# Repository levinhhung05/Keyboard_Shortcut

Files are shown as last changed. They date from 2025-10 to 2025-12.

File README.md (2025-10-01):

# Keyboard_Shortcut
Mục đích: Phát triển một bàn phím thông minh để thực thi các tác vụ và phím tắt một cách nhanh chóng, giúp tối ưu hóa trải nghiệm và nâng cao năng suất làm việc.

Thành phần chính:
- Vi điều khiển trung tâm: ATMEGA 328P.
- Thiết bị nhập liệu: Bàn phím ma trận 4x4 và 2 bộ encoder.
- Nguyên lý hoạt động:
  + Vi điều khiển (MCU) đọc dữ liệu đầu vào từ bàn phím và encoder.
  + Dữ liệu được truyền đến PC/Laptop thông qua giao tiếp UART.
  + Chương trình Python trên máy tính sẽ nhận dữ liệu này và thực hiện các hành động tương ứng như nhấn tổ hợp phím, điều khiển âm lượng, hoặc mở ứng dụng.

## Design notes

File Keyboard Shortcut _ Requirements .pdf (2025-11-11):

KEYBOARD SHORTCUT

1.Introduction ( Giới thiệu)
Là một thiết bị nhập liệu rút gọn phục vụ cho việc thực hiện các phím tắt và thao tác nhanh trên máy tính, thông qua bàn phím ma trận 4x4 kết hợp với hai bộ mã hóa quay (Rotary Encoder). Thiết bị cho phép người dùng kích hoạt các lệnh như sao chép, dán, mở phần mềm, điều chỉnh âm lượng hoặc phóng to-thu nhỏ chỉ với một thao tác bấm phím hoặc xoay núm.

2.Functional Requirements

Number | Description | Note
FR1 | Hệ thống phải cho phép thực hiện thao tác phím tắt nhanh trên máy tính thông qua bàn phím ma trận 4x4
FR1.1 | Mỗi phím trên bàn phím ma trận 4x4 có thể được ánh xạ (mapping) thành tổ hợp phím tùy chỉnh
FR1.2 | MCU phải thực hiện thuật toán quét bàn phím để phát hiện phím nhấn chính xác theo thời gian thực
FR1.3 | Khi người dùng nhấn phím, dữ liệu phải được gửi đến PC qua UART ngay lập tức.
FR1.4 | Python phải nhận và thực thi đúng hành động được cấu hình tương ứng với mã phím.

FR2 | Hệ thống hỗ trợ điều khiển bằng Rotary Encoder.
FR2.1 | Encoder phải nhận biết chính xác hướng xoay (clockwise/counter–clockwise
FR2.2 | Khi xoay encoder, hệ thống phải gửi mã điều khiển tương ứng lên PC (ví dụ tăng/giảm volume, zoom in/out).
FR2.3 | Nút nhấn trên encoder phải hoạt động như phím chức năng riêng (ví dụ reset zoom hoặc mute)
FR3 | Hệ thống phải truyền dữ liệu giữa MCU và PC qua UART
FR3.1 | Tốc độ truyền dữ liệu UART phải được thiết lập ở mức 9600 baud.
FR3.2 | Dữ liệu truyền phải ở dạng mã ký tự hoặc chuỗi đơn giản để Python dễ phân tích.
FR4 | Phần mềm trên PC phải thực hiện các hành động hệ thống tương ứng.
FR4.1 | Cho phép thực hiện tổ hợp phím như: Ctrl + C, Ctrl + V, Ctrl + A, Alt + F4,…
FR4.2 | Cho phép mở ứng dụng hoặc website qua lệnh Python (subprocess hoặc webbrowser)
FR4.3 | Hỗ trợ điều khiển âm lượng hệ thống qua pyautogui (volumeup, volumedown, mute).
FR5 | Hệ thống phải cho phép tùy chỉnh chức năng các phím.
FR5.1 | Người dùng có thể chỉnh sửa trực tiếp mã Python để thay đổi hành động của từng phím
FR5.2 | Hệ thống phải dễ dàng mở rộng để thêm phím hoặc chức năng mới sau này

3.Non – Functional Requirements

Number | Description | Note
N-FR1 | Hệ thống phải có thời gian phản hồi ≤ 500 ms từ lúc người dùng thao tác đến khi lệnh được thực thi trên máy tính.
N-FR2 | Dữ liệu truyền qua UART phải ổn định, không bị nhiễu, không mất gói trong điều kiện hoạt động bình thường
N-FR3 | Chương trình Python trên PC phải hoạt động liên tục ≥ 300 giờ mà không cần khởi động lại
N-FR4 | Hệ thống phải tương thích với Windows hoặc Linux, không yêu cầu cài đặt thêm driver đặc biệt.
N-FR5 | Thiết bị phải tiêu thụ dòng điện ≤ 100 mA ở 5V để đảm bảo an toàn khi cấp nguồn qua cổng USB
N-FR6 | Kích thước mạch phải gọn, có thể đặt trên bàn làm việc mà không chiếm nhiều diện tích
N-FR7 | Các phím trên bàn phím ma trận phải có độ bền tối thiểu 50.000 lần nhấn
N-FR8 | Encoder phải vận hành mượt, không bị nhảy bước hoặc rung nhiễu khi xoay nhanh
N-FR9 | Thiết bị phải hoạt động ổn định trong dải nhiệt độ 0°C – 50°C

### 4. System architecture

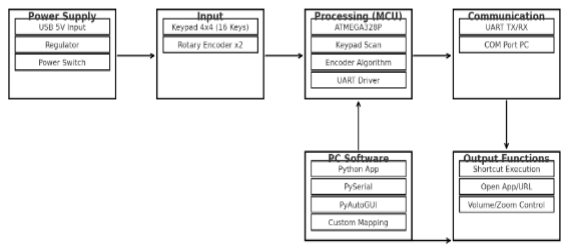
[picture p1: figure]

5.Use case modelling
Use case name | Thực hiên phím tắt bằng Keypad
Use case ID | UC01
Scope | Keyboard Shorcut System
Primary Actor | User
Stakeholder & Interest | User: muốn thao tác nhanh hơn so với dùng bàn phím hoặc chuột. Hệ thống: phải nhận và truyền tín hiệu chính xác, không chậm trễ.
Preconditions | Thiết bị đã được kết nối với máy tính qua UART. Python Script đang chạy
Postconditions | Lệnh phím tắt được thực thi trên máy tính

Main Flow of Events | 1. User nhấn một phím trên keypad. 2. MCU quét phím và mã hóa giá trị phím. 3. MCU gửi mã phím qua UART đến PC. 4. Chương trình Python nhận mã và thực hiện tổ hợp phím tương ứng (VD: Ctrl+C, Alt+F4)
Alternative Flow | User nhấn giữ phím → hệ thống có thể thực thi hành động lặp theo thiết kế (nếu cấu hình)
Exception Flows | Nếu Python không nhận được dữ liệu UART → không có hành động nào xảy ra
Special Requirements | Thời gian phản hồi ≤ 500 ms
Use case name | Điều chỉnh thông số bằng Encoder
Use case ID | UC02
Scope | Keyboard Shorcut System
Primary Actor | User
Stakeholder & Interest | User: muốn chỉnh nhanh các giá trị như âm lượng, zoom, cuộn nội dung

Preconditions | Encoder phải được MCU đọc tín hiệu chính xác (A/B xung)
Postconditions | Thao tác điều chỉnh được thực hiện trên máy tính.
Main Flow of Events | 1. User xoay encoder. 2. MCU đọc hướng xoay và đếm bước xung. 3. MCU gửi ký tự điều khiển tương ứng qua UART (VD: 'X' = Volume Up). 4. Python nhận và thực thi lệnh (volumeup, zoom in/out…)
Alternative Flow | User nhấn nút trên encoder để thực hiện hành động phụ (VD: mute, reset zoom)
Exception Flows | Xung encoder nhiễu → MCU sử dụng debounce logic để lọc.
Special Requirements | Tốc độ xử lý xoay nhanh không được bỏ xung.
Use case name | Tùy chỉnh chức năng phím (Custom Mapping)
Use case ID | UC03
Scope | Keyboard Shorcut System

Primary Actor | User
Stakeholder & Interest | User: muốn cá nhân hóa phím theo thói quen sử dụng.
Preconditions | User truy cập file Python để chỉnh sửa mapping.
Postconditions | Cấu hình mới được lưu và có hiệu lực ngay khi chạy lại script.
Main Flow of Events | 1. User mở file Python mapping. 2. User sửa mã phím → lệnh tương ứng mới. 3. Lưu file và khởi chạy lại chương trình Python. 4. Keypad hoạt động theo cấu hình mới.
Alternative Flow | Có thể lưu nhiều profile mapping để chuyển đổi.
Exception Flows | Nếu user nhập sai mã lệnh, Python có thể báo lỗi và không thực thi.
Special Requirements | File cấu hình phải đơn giản, dễ chỉnh sửa.

6.Hardware Requirements

Vi điều khiển (Atmega328P):

- MCU 8 bit,xung nhịp tối đa 20MHz,bộ nhớ flash 32KB,SRAM 2KB,EEPROM 1KB
- Số chân I/O là 23 chân,đáp ứng kết nối keypad và encoder
- Tích hợp UART để truyền dữ liệu sang PC

Keypad ma trận 4x4(16 phím)
- Sử dụng 8 chân GPIO để quét ma trận
- Điện áp tương thích MCU 3-5V
- Cấu trúc 4 hàng x 4 cột,tổng 16 phím

Rotary Encoder ( 2 bộ)

- Độ phân giải :khoảng 20pulses/rev
- Mỗi encoder gồm kênh A-B và nút nhấn
- Đảm bảo kết nối Encoder 1 -> PD0,PD2,PD4;Encoder 2->PD1,PD3,PD5
- Điều chỉnh nhanh các chức năng như:tăng/giảm volume;zoom in/zoom out

Button(tích hợp trong Encoder)
- Sử dụng cơ chế debounce để giảm nhiễu

7.Software Requiments

Firmware trên Atmega328P

- Khởi tạo cổng I/O,cấu hình các chân keypad và encoder
- Truyền dữ liệu qua UART đến PC với tốc độ 9600bps
- Thực hiện thuật toán quét bàn phím ma trận 4x4 để phát hiện phím nhấn theo thời gian thực

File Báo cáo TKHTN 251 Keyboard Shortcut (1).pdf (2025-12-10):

### ĐẠI HỌC QUỐC GIA TP. HỒ CHÍ MINH

### TRƯỜNG ĐẠI HỌC BÁCH KHOA

### KHOA ĐIỆN – ĐIỆN TỬ

### BỘ MÔN ĐIỆN TỬ

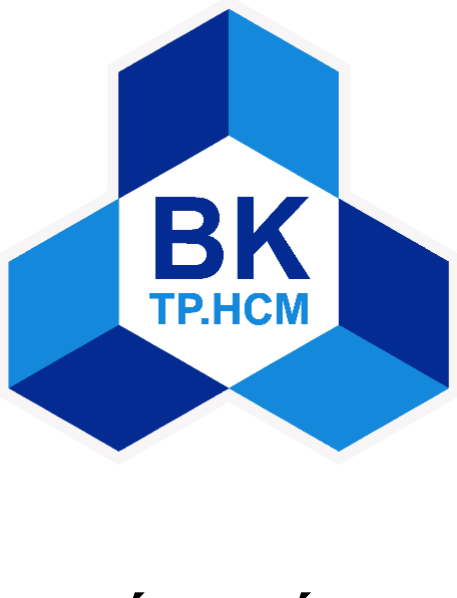
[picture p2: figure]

### BÁO CÁO

### THIẾT KẾ HỆ THỐNG NHÚNG

### KEYBOARD SHORTCUT

### Nhóm 7 GVHD: Ths Bùi Quốc Bảo

TP. Hồ Chí Minh, Tháng 12 Năm 2025

Thiết kế hệ thống nhúng | GVHD :Ths Bùi Quốc Bảo

MỤC LỤC

CHƯƠNG 1 : TỔNG QUAN
LỜI NÓI ĐẦU

Trong thời đại ngày nay, giữa sự phát triển nhanh chóng của các thiết bị điện tử, trải nghiệm người dùng cũng đang được cải thiện tương ứng. Một trong những trải nghiệm người dùng được nhấn mạnh là tốc độ vận hành, đặc biệt là trong các lĩnh vực chuyên môn như thiết kế kỹ thuật số, đòi hỏi phải thực hiện nhanh chóng các hành động cụ thể. Vì lý do này, nhóm chúng tôi giới thiệu một giải pháp: bàn phím tắt, được thiết kế để giúp người dùng thực hiện nhanh chóng một loạt hành động thông qua một bộ phím tắt được thiết lập sẵn. Hơn nữa, sản phẩm cho phép người dùng tùy chỉnh và cấu hình các phím tắt để phù hợp với sở thích cá nhân linh hoạt.

### 1.1 Giới thiệu về dự án

Trong quá trình học tập và làm việc, hoạt động của sinh viên luôn gắn liền với máy tính và việc sử dụng các chức năng có sẵn thông qua các phím tắt. Xuất phát từ nhu cầu cá nhân này và đồng thời với việc học tập môn Thiết kế Hệ thống Nhúng trong học kỳ hiện tại, nhóm 7 đã quyết định chọn đề tài “ Keyboard Shortcut ”.

### 1.2 Mục đích của dự án

Mục tiêu chính của dự án này là phát triển một bàn phím thông minh, kết hợp tính linh hoạt của bàn phím ma trận 4x4 với khả năng điều khiển đa chức năng của hai bộ mã hóa quay. Điều này sẽ cung cấp một công cụ nhập liệu hiệu quả, tối ưu hóa trải nghiệm của người dùng và nâng cao năng suất làm việc hàng ngày.

### 1.3 Lý do chọn dự án

Nhóm 7 chúng em chọn chủ đề này dựa trên kinh nghiệm cá nhân và nhu cầu thường xuyên sử dụng các chức năng khác nhau có sẵn trên máy tính. Là sinh viên kỹ thuật, các thành viên nhóm thường xuyên tiếp xúc với các công nghệ mới, đòi hỏi khả năng sáng tạo để hợp lý hóa quy trình làm việc. Việc tích hợp bàn phím ma trận và bộ mã hóa quay trong bàn phím tắt không chỉ tối ưu hóa thao tác nhập liệu mà còn mở ra nhiều khả năng đa chức năng. Điều này rất quan trọng trong phạm vi của môn học "Thiết kế Hệ thống Nhúng", nơi nhóm có thể áp dụng dự án vào các dự án cá nhân hoặc thậm chí là công việc nghiên cứu và phát triển. Các khóa học cơ bản về điện tử, vi xử lý và thiết kế kỹ thuật số đã cung cấp cho nhóm một nền tảng lý thuyết vững chắc và các kỹ thuật thiết kế cho hệ thống nhúng. Dự án này đóng vai trò là cầu nối giữa kiến thức đã học và ứng dụng thực tế.

### 1.4 Thành viên nhóm – nhiệm vụ - đánh giá % thực hiện

Họ và Tên | MSSV | Nhiệm vụ | Đánh giá
Trần Phạm Ngọc Vũ | 2214010 | Lên ý tưởng, soạn nội dung, hardware design | 100%
Lê Vĩnh Hưng | 2010305 | Software design ,lên ý tưởng,test sản phẩm/demo | 100%

CHƯƠNG 2:TỔNG QUAN HỆ THỐNG

### 2.1 Requirements của hệ thống

### 2.1.1 Functional Requirements

Number | Description
FR1 | Hệ thống phải cho phép thực hiện thao tác phím tắt nhanh trên máy tính thông qua bàn phím ma trận 4x4
FR1.1 | Mỗi phím trên bàn phím ma trận 4x4 có thể được ánh xạ (mapping) thành tổ hợp phím tùy chỉnh
FR1.2 | MCU phải thực hiện thuật toán quét bàn phím để phát hiện phím nhấn chính xác theo thời gian thực
FR1.3 | Khi người dùng nhấn phím, dữ liệu phải được gửi đến PC qua UART ngay lập tức.
FR1.4 | Python phải nhận và thực thi đúng hành động được cấu hình tương ứng với mã phím.
FR2 | Hệ thống hỗ trợ điều khiển bằng Rotary Encoder.
FR2.1 | Encoder phải nhận biết chính xác hướng xoay (clockwise/counter–clockwise
FR2.2 | Khi xoay encoder, hệ thống phải gửi mã điều khiển tương ứng lên PC (ví dụ tăng/giảm volume, zoom in/out).
FR2.3 | Nút nhấn trên encoder phải hoạt động như phím chức năng riêng (ví dụ reset zoom hoặc mute)
FR3 | Hệ thống phải truyền dữ liệu giữa MCU và PC qua UART

FR3.1 | Tốc độ truyền dữ liệu UART phải được thiết lập ở mức 9600 baud.
FR3.2 | Dữ liệu truyền phải ở dạng mã ký tự hoặc chuỗi đơn giản để Python dễ phân tích.
FR4 | Phần mềm trên PC phải thực hiện các hành động hệ thống tương ứng.
FR4.1 | Cho phép thực hiện tổ hợp phím như: Ctrl + C, Ctrl + V, Ctrl + A, Alt + F4,…
FR4.2 | Cho phép mở ứng dụng hoặc website qua lệnh Python (subprocess hoặc webbrowser)
FR4.3 | Hỗ trợ điều khiển âm lượng hệ thống qua pyautogui (volumeup, volumedown, mute).
FR5 | Hệ thống phải cho phép tùy chỉnh chức năng các phím.
FR5.1 | Người dùng có thể chỉnh sửa trực tiếp mã Python để thay đổi hành động của từng phím
FR5.2 | Hệ thống phải dễ dàng mở rộng để thêm phím hoặc chức năng mới sau này

### 2.1.2 Non – Functional Requirements

Number | Description
N-FR1 | Hệ thống phải có thời gian phản hồi ≤ 500 ms từ lúc người dùng thao tác đến khi lệnh được thực thi trên máy tính.

N-FR2 | Dữ liệu truyền qua UART phải ổn định, không bị nhiễu, không mất gói trong điều kiện hoạt động bình thường
N-FR3 | Chương trình Python trên PC phải hoạt động liên tục ≥ 300 giờ mà không cần khởi động lại
N-FR4 | Hệ thống phải tương thích với Windows hoặc Linux, không yêu cầu cài đặt thêm driver đặc biệt.
N-FR5 | Thiết bị phải tiêu thụ dòng điện ≤ 100 mA ở 5V để đảm bảo an toàn khi cấp nguồn qua cổng USB
N-FR6 | Kích thước mạch phải gọn, có thể đặt trên bàn làm việc mà không chiếm nhiều diện tích
N-FR7 | Các phím trên bàn phím ma trận phải có độ bền tối thiểu 50.000 lần nhấn
N-FR8 | Encoder phải vận hành mượt, không bị nhảy bước hoặc rung nhiễu khi xoay nhanh
N-FR9 | Thiết bị phải hoạt động ổn định trong dải nhiệt độ 0°C – 50°C

### 2.2 Block diagram của hệ thống

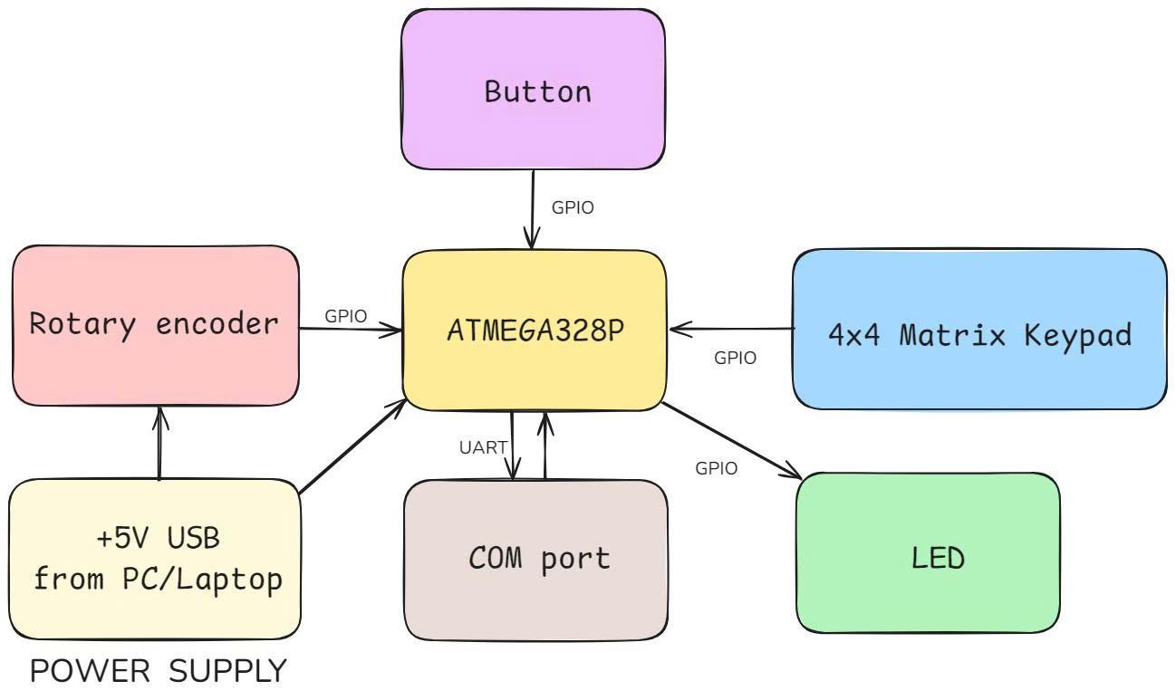
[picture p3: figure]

1. Bàn phím ma trận: Khi người dùng nhấn một phím trên bàn phím ma trận, nó sẽ gửi mã ASCII tương ứng đến MCU.
2. Bộ mã hóa: Khi xoay bộ mã hóa theo chiều kim đồng hồ hoặc ngược chiều kim đồng hồ, nó sẽ gửi dữ liệu kết quả đến MCU.
3. MCU: Sử dụng thư viện bộ mã hóa để xử lý dữ liệu nhận được từ bộ mã hóa và xử lý dữ liệu từ cả bộ mã hóa và MCU, truyền dữ liệu đã xử lý đến PC/Máy tính xách tay thông qua giao tiếp UART.

2.3 . Schematic của hệ thống

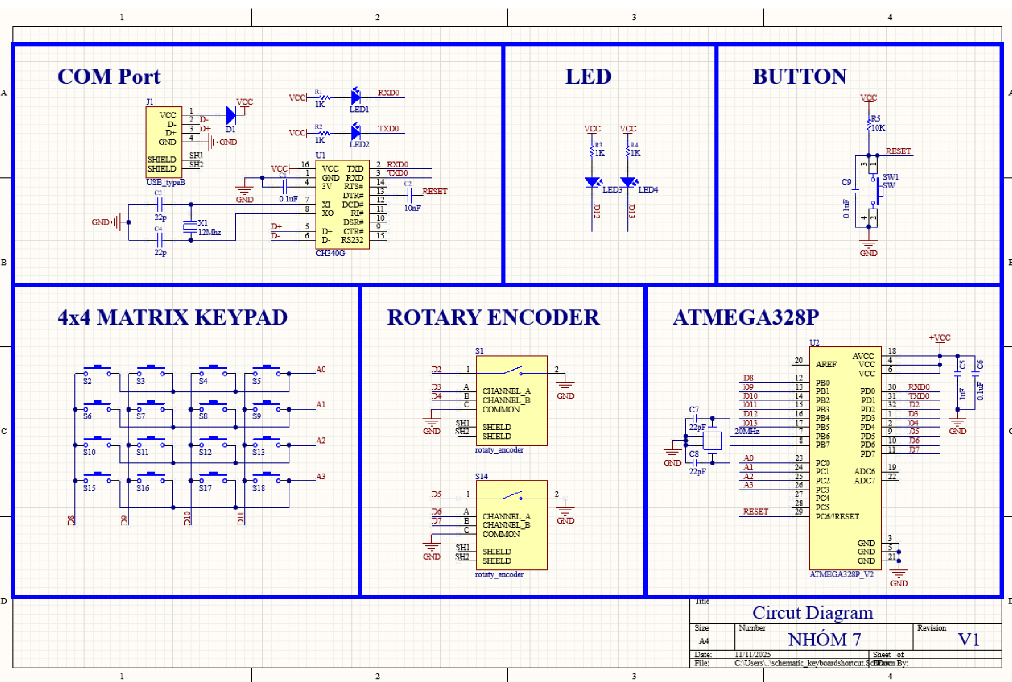
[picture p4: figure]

CHƯƠNG 3 : THIẾT KẾ PHẦN CỨNG

### 3.1 Đặc điểm kỹ thuật của sản phẩm

Function | Thực hiện các tác vụ, phím tắt nhanh chóng
Input | Bàn phím ma trận 4x4
Output | Laptop hoặc PC
User interface | Bàn phím ma trận 4x4
External interface | UART

1. Thuật toán quét bàn phím: Hệ thống phải triển khai thuật toán quét bàn phím để phát hiện chính xác các phím đã nhấn trên ma trận bàn phím 4x4. Thuật toán này chịu trách nhiệm xác định chính xác các phím đã nhấn và thực hiện xử lý thời gian thực.
2. Xử lý thời gian thực: Hệ thống phải hỗ trợ xử lý thời gian thực để đảm bảo phản hồi tức thời với đầu vào của người dùng. Điều này bao gồm giảm thiểu độ trễ trong việc phát hiện các phím đã nhấn và truyền dữ liệu đến PC/Laptop được kết nối.
3. Truyền dữ liệu đến PC/Laptop qua UART: Giao tiếp dữ liệu giữa hệ thống nhúng và PC/Laptop phải được thực hiện qua UART (Bộ thu-phát đồng bộ không đồng bộ toàn cầu). Điều này đảm bảo việc truyền dữ liệu đáng tin cậy và không đồng bộ, tạo điều kiện giao tiếp liền mạch giữa hai thiết bị.
4. Chức năng tùy chỉnh của các phím: Bàn phím tắt phải cung cấp tính linh hoạt trong việc sửa đổi chức năng của từng phím. Tính năng này cho phép người dùng, trong trường hợp này là sinh viên ngành kỹ thuật viễn thông, tùy chỉnh và điều chỉnh bàn phím theo nhu cầu .
5. Thuật toán mã hóa: Hệ thống phải tích hợp một thuật toán mã hóa để xử lý đầu vào từ hai bộ mã hóa quay. Thuật toán phải chuyển đổi chính xác chuyển động quay của các bộ mã hóa thành các hành động có ý nghĩa, nâng cao tương tác của người dùng.

### 3.2 Mô tả phần cứng

Device names | Technical specifications
Giao diện bàn phím số | Temperature Range:0-70 độ C Output :8pins Size :77x 69 mm

ATMEGA 328P | Loại IC :AVR microcontroller Core size : 8 bit Speed: lên đến 20MHz Số chân I/O:23 Program memory size:32KB EEPROM size: 1KB x 8 RAM size :2K x 8 Supply voltage: 1.8V đến 5.5V
Encoder | Supply voltage 3V đến 5V Resolution :20 pulse/rev
1. MCU ATMEGA 328P đọc dữ liệu từ bộ mã hóa và bàn phím ma trận, và gửi dữ liệu đến PC qua UART.
2. 2 Bộ mã hóa điều chỉnh các chức năng điều chỉnh âm lượng, phóng to và thu nhỏ thông qua núm xoay.
3. Bàn phím ma trận 4x4 bao gồm 16 phím, mỗi phím có khả năng điều khiển một thao tác cụ thể hoặc một tổ hợp phím tùy chỉnh.

### 3.3 Các thành phần chi tiết

Bộ mã hóa quay 360 độ

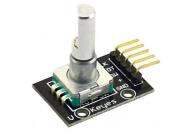
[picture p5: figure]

Mạch âm lượng 360 độ của bộ mã hóa quay là một thành phần quan trọng trong hệ thống điều khiển âm thanh và điện tử, được thiết kế để điều chỉnh âm lượng hoặc các thông số khác một cách linh hoạt và chính xác.

Bàn phím ma trận:

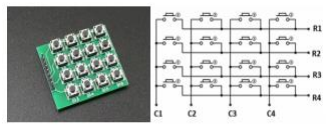
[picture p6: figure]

Khi một phím được nhấn, mạch sẽ tạo một đường dẫn từ hàng tương ứng đến cột. Bộ vi điều khiển hoặc bộ giải mã bàn phím sau đó sẽ đọc các đường dẫn này và xác định phím được nhấn. Mỗi phím có một mã cụ thể được truyền đến hệ thống để xử lý.

### 3.4 Các vấn đề hạn chế

No | Hạn chế
1 | Chi phí thấp, < 1.000.000 VND
2 | Thời gian phản hồi < 600ms
3 | Công suất thấp < 25W

Các vấn đề về chức năng

1. Đảm bảo nhận dạng chính xác và đáng tin cậy các lần nhấn phím để kích hoạt đúng các chức năng đã được ký.

2. Khắc phục các vấn đề liên quan đến việc tùy chỉnh các phím được gán và đảm bảo tích hợp hoàn toàn với phần mềm.

Khi nhấn đồng thời nhiều phím trên cùng một hàng trên bàn phím, bàn phím chỉ ghi nhận phím có giá trị cột thấp nhất

CHƯƠNG 4 : THIẾT KẾ PHẦN MỀM

### 4.1 Mô tả phần mềm

Name | Developer | Application
Proteus | Labcenter Electronics Ltd | Mô phỏng sơ đồ phần cứng với thư viện lớn và đa dạng
Arduino IDE | Arduino community | Đơn giản hóa việc viết mã, tải lên và gỡ lỗi
Visual studio code | Microsoft | Sử dụng Python để nhận tín hiệu từ cổng IO để xử lý mong muốn của người dùng

### 4.2 Flow chart

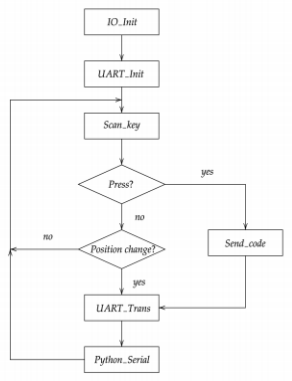
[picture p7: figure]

Giải thích sơ đồ khối:

1. IO init cung cấp thư viện Encoder để nhận biết Bộ mã hóa đang quay hay không và hướng quay của Bộ mã hóa.
2. UART Init khai báo Baudrate cho cổng UART.

3. Phím quét cho phép phát hiện người dùng đã nhấn bàn phím hay chưa. Nếu một phím được nhấn, hãy gửi mã ASCII tương ứng đến MCU.
4. Kiểm tra xem Bộ mã hóa có đang quay hay không và hướng quay của nó, sau đó gửi dữ liệu đến MCU.
5. MCU truyền dữ liệu nhận được đến PC/Laptop qua UART.
6. Kết quả nhận được trên PC/Laptop được xử lý bằng Python sử dụng Python Serial để thực hiện các chức năng tương ứng

### 4.3 Công cụ phần mềm để lập trình và mô phỏng

1. Ngôn ngữ lập trình: C, Python
2. Môi trường phát triển: AVR Studio / Arduino IDE
3. Phần mềm mô phỏng: Proteus hoặc phần mềm mô phỏng tương tự.
4. Phương tiện truyền dữ liệu: Sử dụng mô phỏng cổng COM / giao thức UART trong phần mềm mô phỏng.

CHƯƠNG 5 : KẾT QUẢ THỰC HIỆN

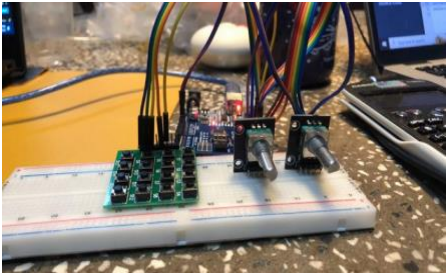
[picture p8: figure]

Video demo của sản phẩm :

…
Ưu điểm
1. Tiết kiệm chi phí sử dụng I/O: Bàn phím ma trận 4x4 cho phép người dùng nhấn đồng thời nhiều phím mà không cần nhiều chân vào/ra. (Một mô-đun 4x4 cần 8 chân so với 16 chân để kết nối từng phím thông thường)
2. Độ tin cậy cao: Với cấu trúc đơn giản và không có bộ phận chuyển động cơ học, bàn phím ma trận thường đảm bảo độ tin cậy cao và tuổi thọ cao.

3. Thân thiện với người dùng: Bàn phím ma trận dễ sử dụng và cài đặt, dễ dàng tích hợp vào nhiều môi trường hệ thống khác nhau với các loại bộ xử lý và bộ điều khiển khác nhau.
4. Tiết kiệm chi phí: Bàn phím ma trận thường có chi phí thấp, khiến chúng trở thành lựa chọn phổ biến trong các ứng dụng có ngân sách hạn chế.

Nhược điểm
1. Số lượng phím hạn chế: Với số lượng phím hạn chế, bàn phím ma trận có thể không phù hợp với các ứng dụng yêu cầu nhiều chức năng hoặc lựa chọn phức tạp.
2. Khả năng nhận dạng phím hạn chế: Trong một số trường hợp, khả năng nhận dạng phím có thể bị hạn chế, đặc biệt là khi nhấn đồng thời nhiều phím trên cùng một hàng.
3. Khả năng chống nước và bụi hạn chế: Một số loại bàn phím ma trận thường không có khả năng chống nước và bụi, điều này có thể gây hạn chế trong môi trường làm việc khắc nghiệt.

CHƯƠNG 6 : KẾT LUẬN
Tóm lại, dự án keyboard shortcut do nhóm 7 chúng em thiết kế đã đạt được mục tiêu chính là thực hiện nhanh chóng các tác vụ và phím tắt thông qua giao diện có thể tùy chỉnh. Nhóm đã triển khai các giải pháp mạnh mẽ để giải quyết nhiều thách thức thiết kế phát sinh trong quá trình phát triển.

Nhìn chung, bàn phím tắt mang lại trải nghiệm người dùng được nâng cao bằng cách cải thiện đáng kể tốc độ hoạt động cho các ứng dụng chuyên biệt. Tính năng tùy chỉnh cũng cho phép linh hoạt đáp ứng các sở thích cá nhân đa dạng.
Trong tương lai, nhóm đặt mục tiêu cải thiện sản phẩm này hơn nữa bằng cách bổ sung kết nối không dây để sử dụng không cần dây. Việc tích hợp các mô-đun Bluetooth sẽ loại bỏ tình trạng dây cáp lộn xộn và mở rộng khả năng tương thích với các thiết bị di động. Với phạm vi đổi mới ngày càng mở rộng, tầm nhìn của nhóm là kết hợp xác thực sinh trắc học như quét vân tay để cho phép nhiều cấu hình tùy chỉnh trên một thiết bị bàn phím. Dự án đầy thách thức này đã mang lại những bài học thực hành vô giá và củng cố năng lực thiết kế hệ thống nhúng của nhóm. Nhóm tự hào đã đạt được các mục tiêu này nhờ nỗ lực không ngừng và tinh thần làm việc nhóm phối hợp.

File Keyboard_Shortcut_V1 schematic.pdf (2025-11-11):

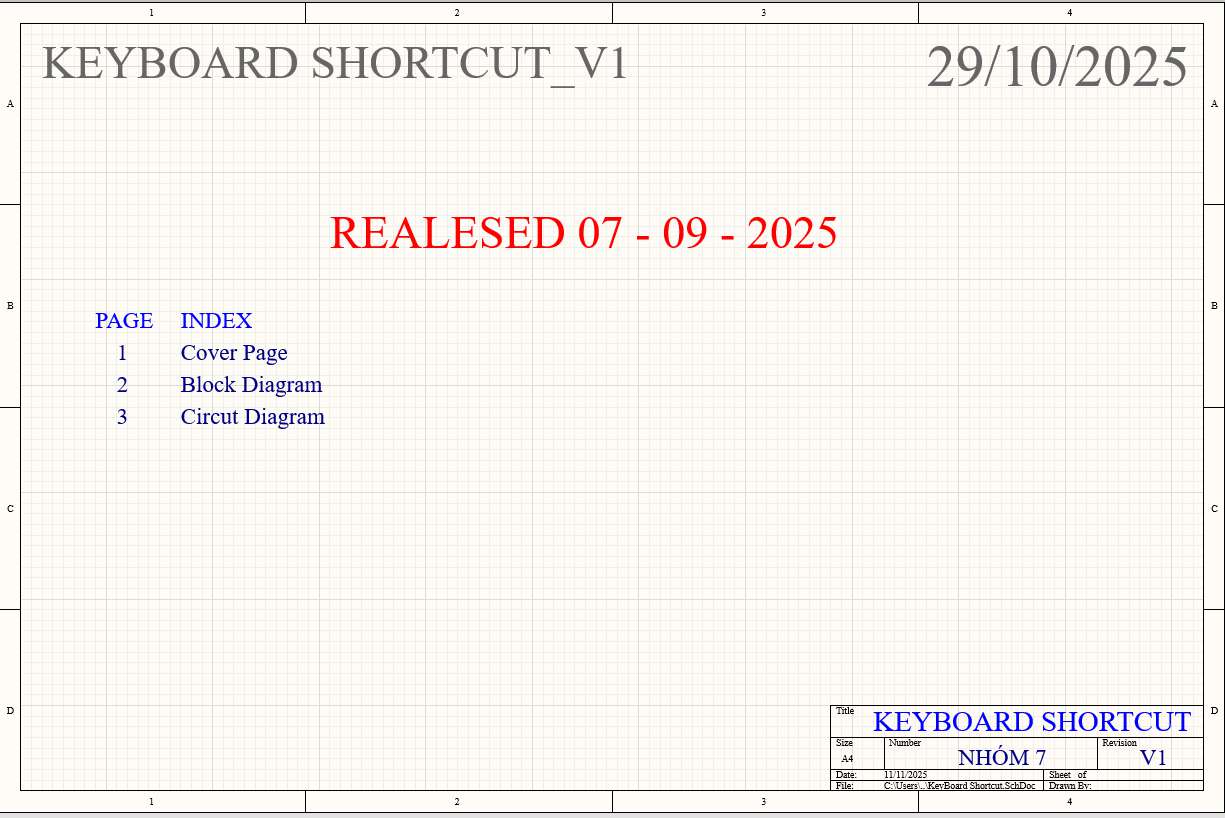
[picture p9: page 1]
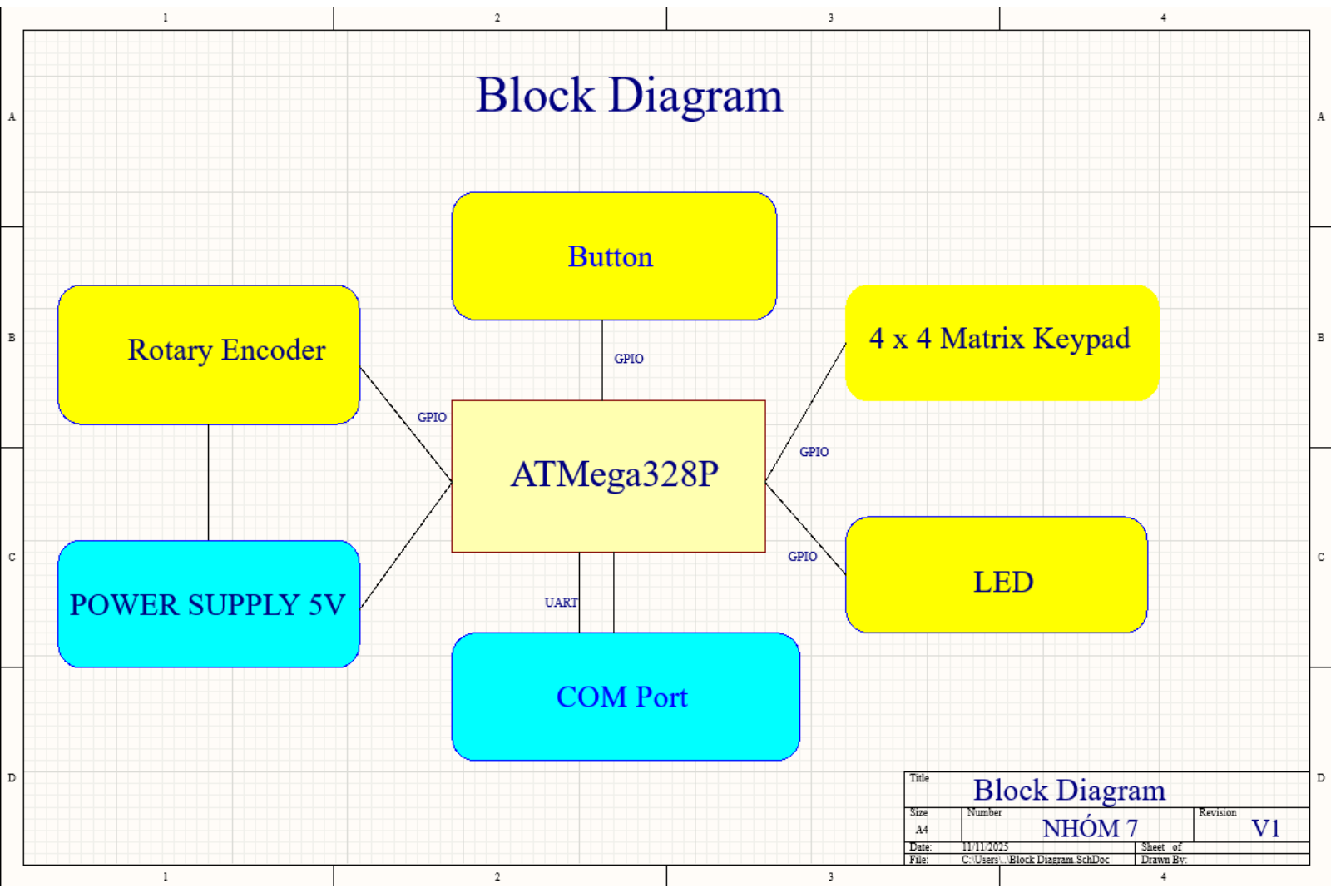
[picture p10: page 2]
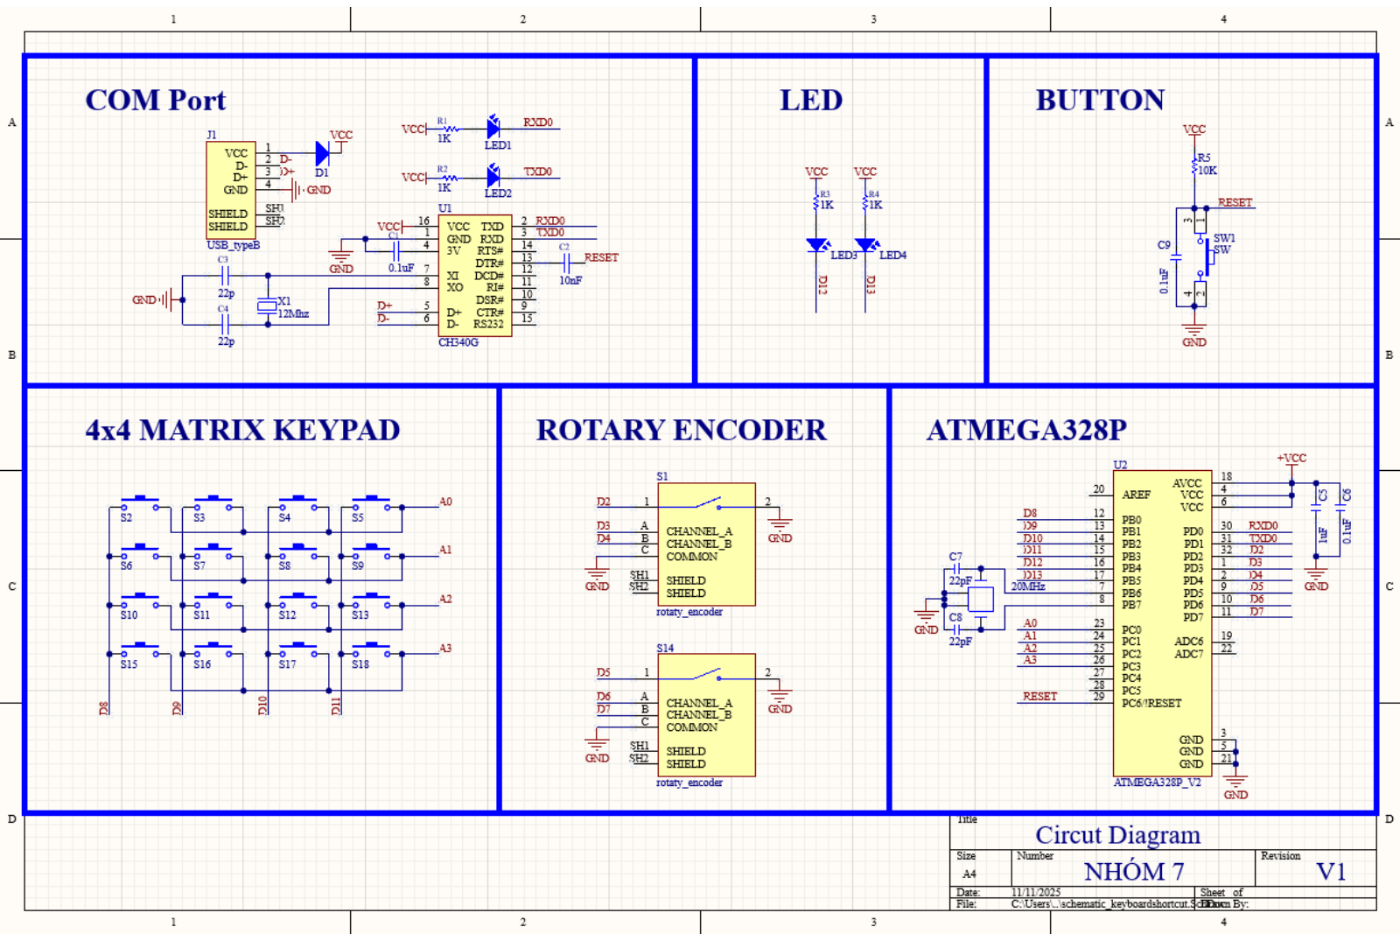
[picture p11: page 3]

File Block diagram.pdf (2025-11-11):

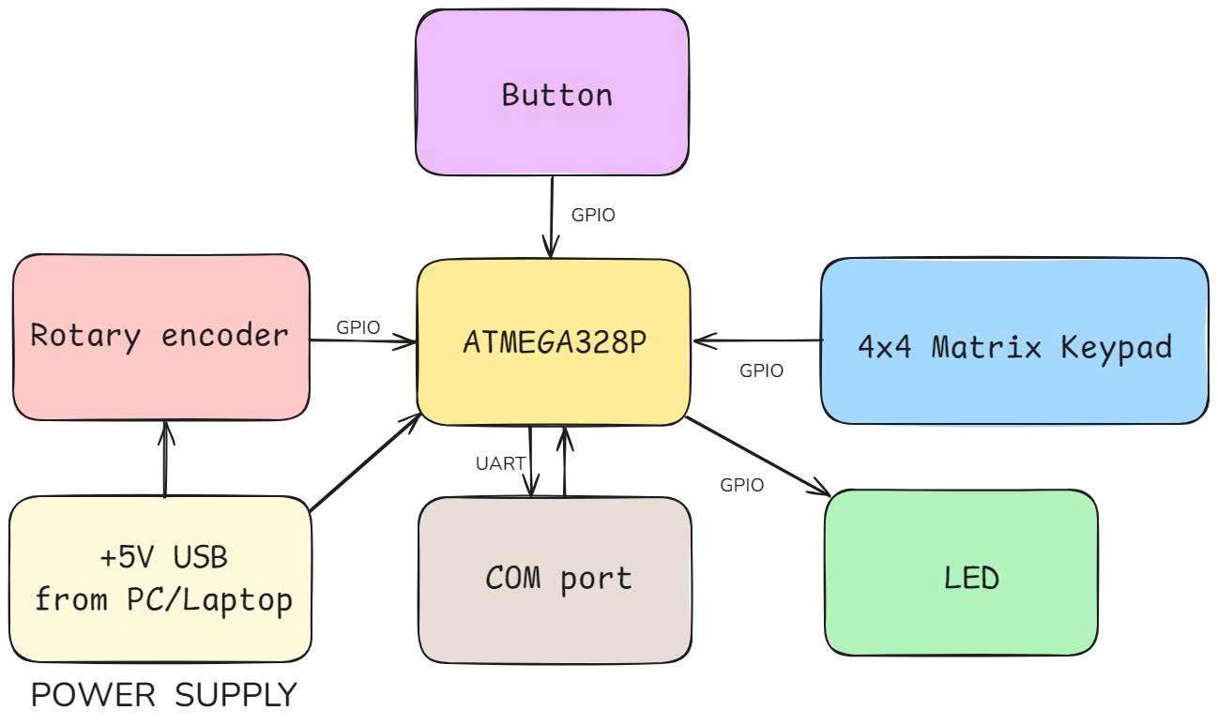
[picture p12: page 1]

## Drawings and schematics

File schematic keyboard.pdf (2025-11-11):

# BUTTON

# VCCD13

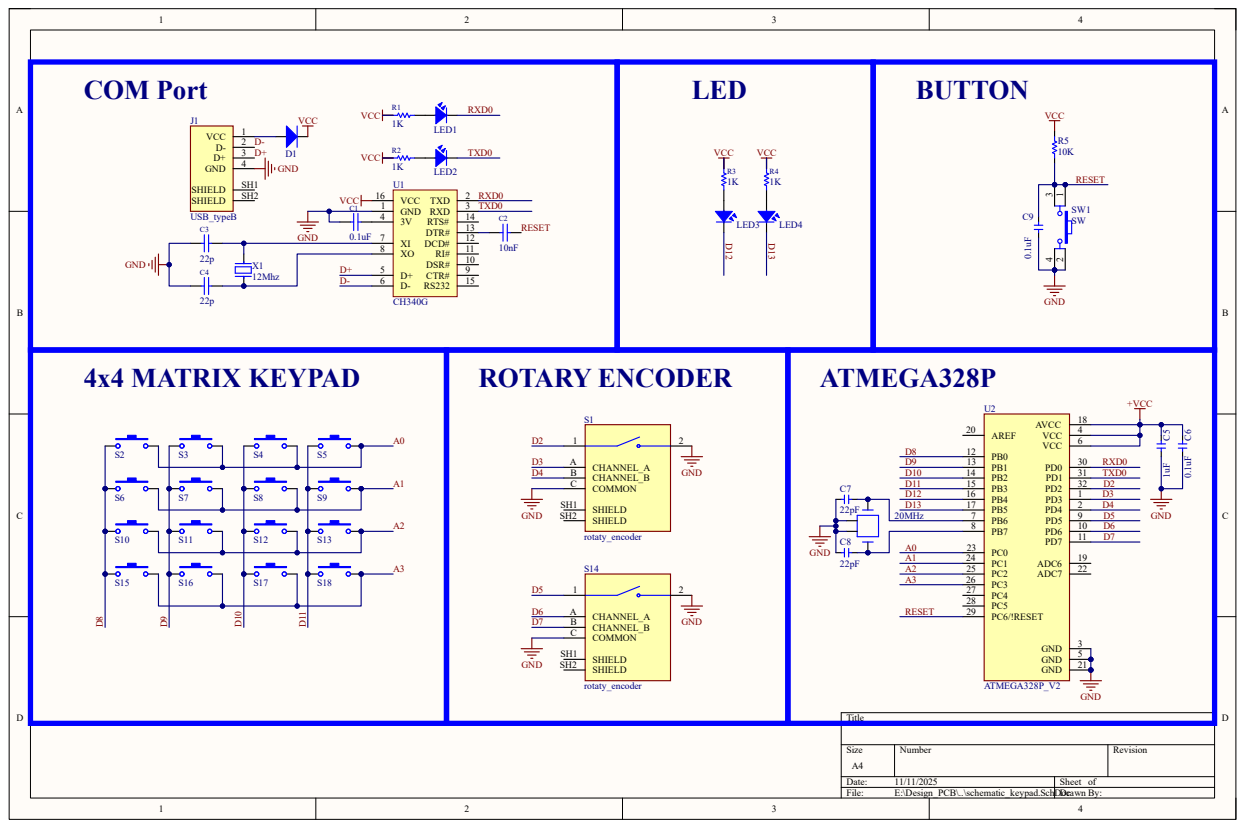
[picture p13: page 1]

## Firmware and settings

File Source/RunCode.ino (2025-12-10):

#define ENCODER_DO_NOT_USE_INTERRUPTS
#include <avr/io.h>
#include <avr/interrupt.h>
#include "lib/Encoder/Encoder.h"
//-----------------------------------------------------------------------------------------------

void IO_Init(){
  //SET PORTB AS INPUT  FOR KEYPAD  3*2
  DDRB  |= (1<<PB0) | (1<<PB1) | (1<<PB2) | (1<<PB3);         //PB0:3 = OUTPUT
  DDRC  &=  ~((1<<PC0) | (1<<PC1) | (1<<PC2) | (1<<PC3));     //PC0:3 = INPUT
  PORTC |= (1<<PC0) | (1<<PC1) | (1<<PC2) | (1<<PC3);
  //SET PORTD AS INPUT FOR ROTATE ENCODER 
  //PD2: INT0 FOR CLK ENCODER 1
  //PD3: INT1 FOR CLK ENCODER 2
  //PD4:PD5 FOR DW ENCODER 1:2
  //PD6:PD7 FOR BUTTON ENCODER  1:2
  DDRD &= ~( (1<<PD2)|(1<<PD3)|(1<<PD4)|(1<<PD5)|(1<<PD6)|(1<<PD7) );
  PORTD = 0XFF;
}
//-------------------------------------------------------------
uint8_t last_key_state = 0; 
uint8_t key_state = 0; 

int8_t Keypad_Scan() {
    // COL = PB0..PB3 (output)
    // ROW = PC0..PC3 (input + pullup)

    // Set all COL pins HIGH
    PORTB |= 0x0F;  // PB0..PB3 = 1

    for (uint8_t col = 0; col < 4; col++) {

        // Pull COL down LOW
        PORTB &= ~(1 << col);
        _delay_us(5);

        uint8_t rowPins = PINC & 0x0F; // đọc PC0..PC3

        if (!(rowPins & (1 << PC0))) return col +  0;  // row 0
        if (!(rowPins & (1 << PC1))) return col +  4;  // row 1
        if (!(rowPins & (1 << PC2))) return col +  8;  // row 2
        if (!(rowPins & (1 << PC3))) return col + 12;  // row 3

        // Pull up
        PORTB |= (1 << col);
    }

    return -1;
}
//-------------------------------------------------------------
void UART_Init() {
    // Baudrate = 9600
    UBRR0H = 0;
    UBRR0L = 103;

    // Active receive and transmit
    UCSR0B = (1 << TXEN0);

    // 8 bit data, 1 bit stop
    UCSR0C = (1 << UCSZ01) | (1 << UCSZ00);
}

void UART_Trans(uint8_t data) {
    while (!(UCSR0A & (1 << UDRE0)));
    // Transmit the character over UART
    UDR0 = data;
}

//-------------------------------------------------------------
Encoder upDown(2,4);
Encoder leftRight(3,5);
long posUpDown = 0; //Position counter for up/down encoder
long posLeftRight = 0; //Position counter for left/right encoder
long posUpDownPrev = 0; //Previous position of up/down encoder
long posLeftRightPrev = 0; //Previous position of left/right encoder

int counterUpDown = 0;
int counterLeftRight = 0;

//-------------------------------------------------------------
int main() {
    int8_t key;
    int8_t last_key = -1;
    uint32_t key_press_time = 0;

    IO_Init();
    UART_Init();
    sei();

    while (1) {
        
		key = Keypad_Scan();

        if (key != -1) { // Nếu có phím được nhấn
            if (last_key == -1) { // Phím mới vừa được nhấn lần đầu
                last_key = key;
                key_press_time = 0;

            } else if (key == last_key) { // Phím đang được giữ
                key_press_time++;

                if (key_press_time >= 500) { // Giữ 1 giây
                    key_press_time = 0;

                    // ----- MAPPING OUTPUT -----
                    if (key >= 0 && key <= 9) {
                        UART_Trans('0' + key);  // 0–9
                    }
                    else if (key >= 10 && key <= 15) {
                        UART_Trans('A' + (key - 10)); // 10→A ... 15→F
                    }
                    UART_Trans('\n');
                    // ---------------------------
                }

            } else { // Phím khác được nhấn
                last_key = key;
                key_press_time = 0;
            }

        } else { // Không có phím nào
            last_key = -1;
        }

        _delay_ms(1);
        

  // ENCODERS
  posUpDown = upDown.read(); //Up/down encoder
  if (posUpDown!=posUpDownPrev) //If new position doesn't equal previous position
  {
    if ((posUpDown-posUpDownPrev)>0)
    {
      counterUpDown = counterUpDown+1;
      if (counterUpDown>3) // 3 counts per physical encoder "click"
      {
        UART_Trans('L');
        UART_Trans('\n');
        counterUpDown = 0;
      }
    }
    else if ((posUpDown-posUpDownPrev)<0)
    {
      counterUpDown = counterUpDown-1;
      if (counterUpDown<-3)
      {
        UART_Trans('X');
        UART_Trans('\n');
        counterUpDown = 0;
      }
    }
  }
  posUpDownPrev = posUpDown;

  posLeftRight = leftRight.read(); // Left/right encoder
  if (posLeftRight!=posLeftRightPrev) //If new position doesn't equal previous position
  {
    if ((posLeftRight-posLeftRightPrev)>0)
    {
      counterLeftRight = counterLeftRight+1;
      if (counterLeftRight>3) // 3 counts per physical encoder "click"
      {
        UART_Trans('P');
        UART_Trans('\n');
        counterLeftRight = 0;
      }
    }
    else if ((posLeftRight-posLeftRightPrev)<0)
    {
      counterLeftRight = counterLeftRight-1;
      if (counterLeftRight<-3)
      {
        UART_Trans('T');
        UART_Trans('\n');
        counterLeftRight = 0;
      }
    }
  }
  posLeftRightPrev = posLeftRight;
  }
  return 0;
}

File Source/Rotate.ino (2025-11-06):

#define ENCODER_DONT_USE_INTERRUPTS
#include <avr/io.h>
#include <avr/interrupt.h>
#include <Encoder.h>

Encoder upDown(2,4);
long posUpDown = 0; //Position counter for up/down encoder
long posLeftRight = 0; //Position counter for left/right encoder
long posUpDownPrev = 0; //Previous position of up/down encoder
long posLeftRightPrev = 0; //Previous position of left/right encoder

int counterUpDown = 0;
int counterLeftRight = 0;
int counter = 0;
//-------------------------------------------------------------------------------
void IO_Init(){
  //SET PORTB AS INPUT  FOR KEYPAD  3*2
  DDRB  |= (1<<PB0)|(1<<PB1)|(1<<PB2); //PB0:2 = OUTPUT
  DDRB  &=  ~( (1<<PB3)|(1<<PB4) );    //PB3:4 = INPUT
  PORTB = 0XFF;
  //SET PORTD AS INPUT FOR ROTATE ENCODER 
  //PD2: INT0 FOR CLK ENCODER 1
  //PD3: INT1 FOR CLK ENCODER 2
  //PD4:PD5 FOR DW ENCODER 1:2
  //PD6:PD7 FOR BUTTON ENCODER  1:2
  DDRD &= ~( (1<<PD2)|(1<<PD3)|(1<<PD4)|(1<<PD5)|(1<<PD6)|(1<<PD7) );
  PORTD = 0XFF;
}
//-------------------------------------------------------------------------------

uint8_t last_key_state = 0; // Trạng thái cuối cùng của phím
uint8_t key_state = 0; // Trạng thái hiện tại của phím

int8_t Keypad_Scan() {
	
	uint8_t col_mask = 0b11111011; // initial row mask
	int8_t scan_col;			//scanning col index
	
	//DDRB = 0x07; // set upper 4 bits of PORTA as input with pull-up, lower 4 bits as output
	//PORTB = 0xFF;//enable pullup resistor on the input pin

	for (scan_col=2;scan_col>=0;scan_col--) {
		PORTB = col_mask; // scan current col
		_delay_us(1); // wait for stable input

		if ((PINB & (1 << PINB3)) == 0) { // check row 0
			return  (scan_col) ; // calculate key value as (row index * 4) + column index
			} 
		else if ((PINB & (1 << PINB4)) == 0) { // check row 1
			return  (3 + scan_col) ; // calculate key value as (row index * 4) + column index
			} 
		col_mask = ((col_mask >> 1) | (1<<7)) ; // shift row mask to scan next row
		}

	return -1;
}



//-------------------------------------------------------------------------------

void UART_Init() {
    // Baudrate = 9600
    UBRR0H = 0;
    UBRR0L = 103;

    // Kích hoạt truyền và nhận
    UCSR0B = (1 << TXEN0);

    // Cấu hình định dạng khung: 8 bit dữ liệu, 1 bit dừng
    UCSR0C = (1 << UCSZ01) | (1 << UCSZ00);
}

void UART_Trans(uint8_t data) {
    while (!(UCSR0A & (1 << UDRE0)));
    // Transmit the character over UART
    UDR0 = data;
}
//-------------------------------------------------------------------------------

void Interrupt_Init(){
    // Enable interrupt on INT0 pin
  EIMSK |= (1 << INT0);

  // Trigger interrupt on rising edge
  EICRA |= (1 << ISC01) | (1 << ISC00);


}

ISR(INT0_vect) {
    // Delay for debouncing
    _delay_ms(50);

  // ENCODERS
  posUpDown = upDown.read(); //Up/down encoder
  if (posUpDown!=posUpDownPrev) //If new position doesn't equal previous position
  {
    if ((posUpDown-posUpDownPrev)>0)
    { 
      counterUpDown = counterUpDown+1;
      if (counterUpDown>3) // 3 counts per physical encoder "click"
      {

        counterUpDown = 0;
      counter++;
      Serial.println('X');

      }
    }
    else if ((posUpDown-posUpDownPrev)<0)
    {

      counterUpDown = counterUpDown-1;
      if (counterUpDown<-3)
      {
      counter--;

        counterUpDown = 0;
        Serial.println('L');
      }
    }
}
//-------------------------------------------------------------------------------
void main() {
    int8_t key;
    int8_t last_key = -1;
    uint32_t key_press_time = 0;

    IO_Init();
    UART_Init();
    Interrupt_Init();

    while (1) {
        key = Keypad_Scan();

        if (key != -1) { // Nếu có phím được nhấn
            if (last_key == -1) { // Nếu đây là lần đầu tiên phím được nhấn
                last_key = key;
                key_press_time = 0;
                PORTC = key; // Xuất kết quả ra PORTC

            } else if (key == last_key) { // Nếu phím vẫn đang được giữ
                key_press_time++;
                if (key_press_time >= 1000) { // Nếu phím được giữ trong 1s
                    key_press_time = 0;
                    PORTC = key;// Xuất kết quả ra PORTC
                    UART_Trans('0'  + key);
                    UART_Trans('\n');

                }
            } else { // Nếu một phím khác được nhấn
                last_key = key;
                key_press_time = 0;
                PORTC = key; // Xuất kết quả ra PORTC

            }
        } else { // Nếu không có phím nào được nhấn
            last_key = -1;
            PORTC = 0XFF;

        }
        
        _delay_ms(1); // Đợi 1ms trước khi quét lại
    }

}

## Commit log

2025-11-05 Update Block Diagram with component descriptions
    Added descriptions for matrix keypad and encoder components.
2025-11-06 Flow chart.png
2025-12-10 update
    Updated the keypad scanning logic and improved the initialization of I/O ports. Changed the include path for the Encoder library.
